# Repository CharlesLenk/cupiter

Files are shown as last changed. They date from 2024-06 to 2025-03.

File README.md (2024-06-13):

# Cupiter

Cupiter is a 3D Printable poseable action figure that resembles a robot. In this repository you'll find:
* [Printing and assembly instructions](instructions/README.md).
* The full [source code](src/README.md) for this project.

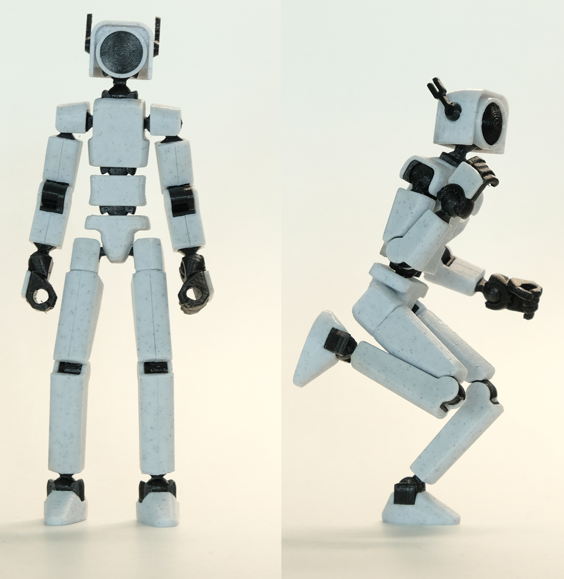
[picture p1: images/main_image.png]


## About

I've been working on Cupiter off and on (mostly off) for several years. At first, my goal was just to create a very simple desk toy inspired by Lego Bionicles. My CAD skills improved as I worked on the project though, which inspired me to keep going and redesigning at my current skill level. It's still possible to take it further, but I'm happy with Cupiter as it is now and am ready to share with the world.

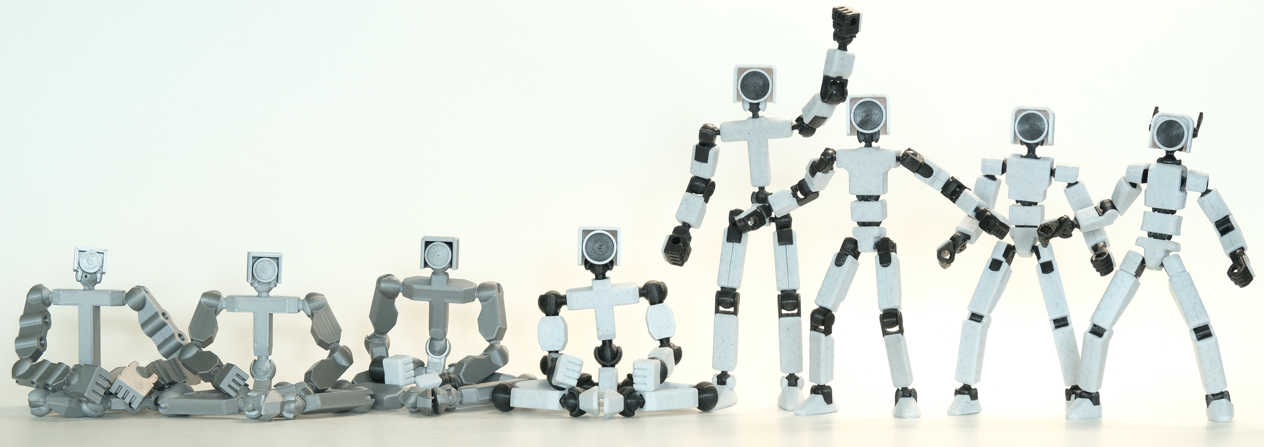
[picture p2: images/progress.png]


### Inspirations

* Lego Bionicles were some of my favorite toys growing up. The early designs of Cupiter were even lego-like, including pegs with snaps to attach additional parts, and simple ball and socket joints.
* Aaron Thomas' [Endo](https://www.toyforge.in/products/endo-the-skeleton). Endo is a more advanced project than mine, made by a more talented designer, but I did find it inspiring since if it was possible to push 3D printing this far, I knew what I was going for was achievable. This project heavily inspired the elbow and knee joints used for some of the middle versions of Cupiter.
* Soozafone's [Lucky 13](https://www.printables.com/model/148367-lucky-13-printable-jointed-figure). Lucky 13 came out a few years after I started this project and, after a mild round of despair having been beaten to the punch, it inspired me to revisit my work. Printing and assembling the two projects, you'll find the designs substantially different in construction, but I absolutely took visual cues from Lucky 13 like the second waist joint, posable shoulders, and more human-like proportions.

### Special Thanks

* I owe a lot to the developers and maintainers of [OpenSCAD](https://openscad.org/). It's been amazing having a project like this as a free resource.

## License
Source code and generated models are licensed under [CC-BY-4.0](https://creativecommons.org/licenses/by/4.0/).

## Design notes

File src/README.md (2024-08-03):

# About the Code
Because OpenSCAD is designed for parametric CAD, but the visual design for Cupiter is part sculpting, the code is a mix of well designed parameterized functions, and magic number hacks because something looked better if it was 0.2 millimeters larger. Where possible, I've attempted to have parts scale and adjust appropriately, but many edits will require manual tweaks for visual design.

## Cloning the Repository

This project uses a submodule for some common OpenSCAD code. If the submodule is not initialized, the `openscad-utilities` directory will be empty, and the project won't compile. To get the submodule code when cloning, add the `--recurse-submodules` option to the clone command. If you've already cloned the project, run the command `git submodule update --init` in the project root to pull down the submodule.

## Editing the Project
This project is written in native OpenSCAD and can be edited without any additional software, however I recommend using [VSCode](https://code.visualstudio.com/) with Leathong's [OpenSCAD extension](https://marketplace.visualstudio.com/items?itemName=Leathong.openscad-language-support).

OpenSCAD has an "Automatic Reload and Preview" option that will refresh the preview whenever a file is updated, even if the updates come from an external tool. In this way, you can have multiple instances of OpenSCAD showing previews of different parts in different files, and have all previews refresh to show your edits whenever you save in VSCode, which makes viewing changes to assemblies of multiple parts much easier.

### Navigating the Files
* antenna.scad
    * The antenna that go on the sides of the head options.
* arms.scad
    * The arms, including the shoulder that connects to the torso.
* assembly image map.scad
    * Provides a selector between multiple assembly views. Used by the script that exports assembly instruction images.
* assembly.scad
    * Provides an assembled view of the project.
* body.scad
    * The three main torso segments.
* camera head.scad
    * A head option that resembles a camera.
* feet.scad
    * The feet.
* globals.scad
    * Contains global variables for the project.
* hands.scad
    * All complex and simple hand options.
* legs.scad
    * The legs, including the hip that connects to the torso.
* limbs.scad
    * Shared code for the arms and legs.
* print map.scad
    * Imports all the other parts and rotates them into correct orientations for printing in order to simplify the export script.
* robot common.scad
    * Some common modules that didn't fit well into other files.
* snaps.scad
    * Code for the snap bumps that help hold parts together.
* space head.scad
    * An alternate head option.

## Generating the Parts

There are two options for generating the parts. Either through a provided export script, or manually through the OpenSCAD UI.

As of 2024, the OpenSCAD development preview uses a new rendering engine called Manifold, which is many times faster. When exporting or working on this project, it's recommended that you use a development snapshot of OpenSCAD with Manifold enabled. This project is tested as working with version `2024.05.02 (git 1057a82e9)` specifically, in the event that issues are encountered with newer versions.

### Exporting with the Script

In order to generate the parts, a [Python](https://www.python.org/) export script is provided in `src/python/stl_export.py`.

When first run, the export script will confirm the output directory and attempt to find OpenSCAD on your system. As long as OpenSCAD is installed in the standard applications directory for your system and you have a Desktop folder, the defaults provided should work without customization. The values are saved to `export.conf` in the project root, which can be edited directly if you need to change the OpenSCAD location or output directory.

The export will have the folder structure given in the [instructions](../instructions/README.md)

### Exporting Manually

This option is not recommended. `print map.scad` is invoked by the export script to generate each part. In this file, there is a large `if/else` condition where the call to generate each part can be seen. You can either write OpenSCAD code using these calls to build up a print plate, or the part selector can be manually edited to select each part, which can then be rendered and exported through the OpenSCAD UI like any other project.

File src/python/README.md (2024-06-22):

# Export Scripts

* stl_export.py
    * Exports STLs for the project.
* assembly_image_export.py
    * Exports images for the assembly guide.
* export_config.py
    * Functions for reading and writing export config values. Does nothing if run directly.

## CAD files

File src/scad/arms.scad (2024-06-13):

include <openscad-utilities/common.scad>
include <limbs.scad>
use <hands.scad>

elbow_max_angle = 160;

elbow_joint_offset = -2;

arm_armor_upper_len = arm_upper_len - ball_dist;
arm_armor_lower_len = arm_lower_len - ball_dist;

arm_width = 10;
arm_upper_top_len = 3.2;
arm_upper_bot_width_back = 1.1;
arm_lower_bot_width_front = 3.5;
arm_lower_bot_width_back = 3.4;

function elbow_max_angle() = elbow_max_angle;

module arm_assembly(
    frame_color = frame_color,
    armor_color = armor_color,
    with_armor = true,
    explode_frame = false,

    shoulder_armor = false,
    explode_shoulder_armor = false,
    arm_upper_armor = false,
    explode_arm_upper_armor = false,
    arm_lower_armor = false,
    explode_arm_lower_armor = false,

    hand = false,
    explode_hand = false,
    hand_armor = false,
    explode_hand_armor = false,

    arm_retract_angle = 0,
    elbow_angle = 0
) {
    shoulder_armor = with_armor && (explode_shoulder_armor ? true : shoulder_armor);
    arm_upper_armor = with_armor && (explode_arm_upper_armor ? true : arm_upper_armor);
    arm_lower_armor = with_armor && (explode_arm_lower_armor ? true : arm_lower_armor);
    hand_armor = with_armor && (explode_hand_armor ? true : hand_armor);
    hand = explode_hand ? true : hand;

    elbow_angle = explode_frame ? 40 : elbow_angle;

    explode_y = 22;
    frame_explode_y = explode_frame ? explode_y : 0;

    explode_z = 20;
    arm_upper_armor_explode_z = explode_arm_upper_armor ? explode_z : 0;
    arm_lower_armor_explode_z = explode_arm_lower_armor ? explode_z : 0;

    shoulder_armor_explode_z = explode_shoulder_armor ? explode_z : 0;

    hand_explode_y = explode_hand ? explode_y : 0;

    rotate(180) color(frame_color) shoulder();
    if (shoulder_armor) {
        translate([0, 0, -shoulder_armor_explode_z]) {
            rotate([0, 180, 180]) color(armor_color) shoulder_armor();
        }
        if(explode_shoulder_armor) {
            translate([0, 0, -shoulder_armor_explode_z/2]) {
                rotate([270, 0, 90]) assembly_arrow();
            }
        }
    }
    rotate([arm_retract_angle, 0, 0]) {
        translate([0, frame_explode_y, 0]) {
            rotate([0, 180, 0]) color(frame_color) arm_upper();
            if (arm_upper_armor) {
                reflect([0, 0, 1]) {
                    translate([0, 0, -arm_upper_armor_explode_z]) {
                        color(armor_color) arm_upper_armor();
                    }
                    if(explode_arm_upper_armor) {
                        translate([0, arm_upper_len/2, -arm_upper_armor_explode_z/2 - 2]) {
                            rotate([270, 0, 90]) assembly_arrow();
                        }
                    }
                }
            }
            if(explode_frame) {
                translate([0, -frame_explode_y/2]) rotate(180) assembly_arrow();
            }
        }
        rotate_with_offset_origin([elbow_joint_offset, arm_upper_len + frame_explode_y, 0], [0, 0, elbow_angle]) {
            if(explode_frame) {
                translate([elbow_joint_offset, arm_upper_len + 1.5 * frame_explode_y, 0]) {
                    rotate(180) assembly_arrow();
                }
            }
            translate([0, arm_upper_len + 2 * frame_explode_y]) {
                color(frame_color) arm_lower();
                if (arm_lower_armor) {
                    reflect([0, 0, 1]) {
                        translate([0, 0, -arm_lower_armor_explode_z]) {
                            color(armor_color) arm_lower_armor();
                        }
                        if(explode_arm_lower_armor) {
                            translate([0, arm_lower_len/2, -arm_lower_armor_explode_z/2 - 2]) {
                                rotate([270, 0, 90]) assembly_arrow();
                            }
                        }
                    }
                }
                if(hand) {
                    translate([0, arm_lower_len + hand_explode_y]) {
                        rotate([90, 180, 0]) {
                            mirror([0, 0, 1]) {
                                hand_assembly(
                                    frame_color = frame_color,
                                    armor_color = armor_color,
                                    armor = hand_armor,
                                    explode = explode_hand_armor
                                );
                            }
                        }
                        if(explode_hand) {
                            translate([0, -hand_explode_y/2]) assembly_arrow();
                        }
                    }
                }
            }
        }
    }
}

arm_upper_bot_width_front = get_limb_width_at_y(
    start_width = arm_width/2,
    end_width = arm_lower_bot_width_front,
    length = arm_armor_upper_len + arm_armor_lower_len - arm_upper_top_len,
    y = arm_armor_upper_len - arm_upper_top_len - hinge_armor_y_offset - 0.1
);
arm_lower_width_mid = get_limb_width_at_y(
    start_width = arm_width/2,
    end_width = arm_lower_bot_width_front,
    length = arm_armor_upper_len + arm_armor_lower_len - arm_upper_top_len,
    y = arm_armor_upper_len - arm_upper_top_len - hinge_armor_y_offset
);

module arm_upper_armor_blank() {
    limb_upper_armor_blank(
        length = arm_armor_upper_len,
        height = segment_height + 2.7,
        top_width = arm_width,
        top_back_length = arm_upper_top_len,
        bottom_front_width = arm_upper_bot_width_front,
        bottom_back_width = arm_upper_bot_width_back,
        joint_offset = elbow_joint_offset
    );
}

module arm_lower_armor_blank() {
    limb_lower_armor_blank(
        length = arm_armor_lower_len,
        height = segment_height + 2.7,
        top_width_front = arm_lower_width_mid,
        width_back = arm_lower_bot_width_back,
        bottom_front_width = arm_lower_bot_width_front,
        joint_offset = elbow_joint_offset
    );
}

module shoulder_socket(is_cut = false) {
    height = segment_height + (is_cut ? segment_cut_height_offset : 0);
    width = socket_d + (is_cut ? segment_cut_width_offset : 0);
    cut_d = is_cut ? 0.2 : 0;

    d = socket_d + 0.5 + cut_d;
    difference() {
        apply_socket_cut(hip_shoulder_tolerance, is_cut = is_cut) {
            rounded_socket_blank(is_cut);
        }
        if (!is_cut) {
            hull() {
                cylinder(d = 4, h = 10);
                rotate([-25, 0, 0]) cylinder(d = 4, h = 10);
            }
        }
        armor_snap_inner(
            length = 4,
            target_width = socket_d,
            depth = 0.6,
            is_cut = !is_cut,
            width_cut_adjust = 0.2
        );
    }
}

module shoulder(is_cut = false) {
    shoulder_socket(is_cut);
    translate([0, socket_r + ball_dist]) {
        rotate(180) ball(is_cut);
    }
}

module shoulder_armor() {
    height = segment_height + 2.6;

    difference() {
        minkowski() {
            armor_blank(socket_d - edge_d + 2.4, segment_height - edge_d + 2.4);
            sphere(d = 1);
        }
        rotate([0, 180, 0]) shoulder(true);
        translate([0, 0, -1.5 * segment_height]) {
            linear_extrude(segment_height) {
                projection(cut = true) {
                    translate([0, 0, segment_height/2]) shoulder(true);
                }
            }
        }
    }

    module armor_blank(x, z) {
        cylinder_length = socket_d/2 - edge_d/2;
        h_ext = 1.2;

        intersection() {
            hull() {
                rotate(180) {
                    rotate_extrude(angle = 180) {
                        intersection() {
                            armor_2d(x, z);
                            translate([0, -z/2]) square([x/2, z]);
                        }
                    }
                }
                rotate([270, 0, 0]) linear_extrude(cylinder_length) armor_2d(x, z);


                translate([0, cylinder_length, h_ext/2]) {
                    rotate([270, 0, 0]) linear_extrude(0.001) armor_2d(x, z + h_ext, d = 6);
                }
            }
            shoulder_cut(
                x,
                pos_y = 2.9,
                neg_y = cylinder_length,
                pos_z = segment_height/2 + h_ext + 1.2 - edge_d/2,
                neg_z = segment_height/2 - edge_d/2 + 0.3,
                ext = 0,
                d = 3
            );
        }
    }
}

module arm_upper(is_cut = false) {
    limb_segment(
        length = arm_upper_len,
        end1_len = ball_dist,
        end2_len = hinge_socket_d/2,
        is_cut = is_cut,
        snaps = true,
        cross_brace = true
    ) {
        ball(is_cut);
        hinge_socket(elbow_joint_offset, is_cut);
    };
}

module arm_upper_armor(is_top = false) {
    apply_armor_cut(is_top) {
        translate([0, ball_dist]) arm_upper_armor_blank();
        mirror([1, 0, 0]) arm_upper(true);
    }
}
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

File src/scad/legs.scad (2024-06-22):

include <openscad-utilities/common.scad>
include <globals.scad>
include <limbs.scad>
use <feet.scad>

knee_joint_offset = -2.3;
knee_max_angle = 165;

leg_upper_top_width = socket_d + 2.4;
upper_thigh_length_back = 6.5;
lower_thight_width_back = 1.2;
leg_lower_armor_len = leg_lower_len - ball_dist;
lower_leg_back_width = 3.7;
lower_leg_lower_width_front = 4;
armor_z = segment_height + 3;

rotator_peg_l = 8;
rotator_peg_d = segment_height + 0.4;
rotator_socket_l = rotator_peg_l + socket_shell_width;
rotator_socket_d = rotator_peg_d + 2 * socket_shell_width + leg_rotator_tolerance;

leg_upper_bot_width_front = get_limb_width_at_y(
    start_width = leg_upper_top_width/2,
    end_width = lower_leg_lower_width_front,
    length = leg_upper_len + leg_lower_armor_len,
    y = leg_upper_len - hinge_armor_y_offset - 0.1
);
leg_lower_width_mid = get_limb_width_at_y(
    start_width = leg_upper_top_width/2,
    end_width = lower_leg_lower_width_front,
    length = leg_upper_len + leg_lower_armor_len,
    y = leg_upper_len - hinge_armor_y_offset
);

function knee_max_angle() = knee_max_angle;

module leg_assembly(
    frame_color = frame_color,
    armor_color = armor_color,
    with_armor = true,
    explode_frame = false,

    hip_armor = false,
    explode_hip_armor = false,
    leg_upper_armor = false,
    explode_leg_upper_armor = false,
    leg_lower_armor = false,
    explode_leg_lower_armor = false,

    foot_socket = false,
    explode_foot_socket = false,
    foot = false,
    explode_foot = false,

    knee_angle = 0
) {
    hip_armor = with_armor && (explode_hip_armor ? true : hip_armor);
    leg_upper_armor = with_armor && (explode_leg_upper_armor ? true : leg_upper_armor);
    leg_lower_armor = with_armor && (explode_leg_lower_armor ? true : leg_lower_armor);
    foot_socket = explode_foot_socket ? true : foot_socket;
    foot = explode_foot ? true : foot;

    hip_offset = socket_d/2 + hip_peg_extension;
    knee_angle = explode_frame ? 40 : knee_angle;

    explode_y = 22;
    explode_z = 20;

    frame_explode_y = explode_frame ? explode_y : 0;
    hip_armor_explode_z = explode_hip_armor ? explode_z : 0;

    foot_socket_explode_y = explode_foot_socket ? explode_y : 0;
    foot_explode_y = explode_foot ? explode_y : 0;

    leg_upper_armor_explode_z = explode_leg_upper_armor ? explode_z : 0;
    leg_lower_armor_explode_z = explode_leg_lower_armor ? explode_z : 0;

    color(frame_color) hip();
    if (hip_armor) {
        translate([0, 0, hip_armor_explode_z]) {
            color(armor_color) hip_armor();
        }
        if(explode_hip_armor) {
            translate([0, 0, hip_armor_explode_z/2]) {
                rotate([90, 0, 90]) assembly_arrow();
            }
        }
    }
    translate([0, hip_offset + frame_explode_y, 0]) {
        rotate([0, 180, 0]) color(frame_color) leg_upper();
        if (leg_upper_armor) {
            reflect([0, 0, 1]) {
                translate([0, 0, -leg_upper_armor_explode_z]) {
                    color(armor_color) leg_upper_armor();
                }
                if(explode_leg_upper_armor) {
                    translate([0, leg_upper_len/2, -leg_upper_armor_explode_z/2 - 2]) {
                        rotate([270, 0, 90]) assembly_arrow();
                    }
                }
            }
        }
        if(explode_frame) {
            translate([0, -frame_explode_y/2 + 4]) rotate(180) assembly_arrow();
        }
    }
    rotate_with_offset_origin([knee_joint_offset, hip_offset + leg_upper_len + frame_explode_y, 0], [0, 0, knee_angle]) {
        if(explode_frame) {
            translate([knee_joint_offset, hip_offset + leg_upper_len + 1.5 * frame_explode_y, 0]) {
                rotate(180) assembly_arrow();
            }
        }
        translate([0, hip_offset + leg_upper_len + 2 * frame_explode_y]) {
            color(frame_color) leg_lower();
            translate([0, foot_socket_explode_y]) {
                if(foot_socket) {
                    translate([0, leg_lower_len, 0]) {
                        rotate([0, 90, 0]) {
                            foot_assembly(
                                frame_color = frame_color,
                                armor_color = armor_color,
                                foot_socket = foot_socket,
                                foot = foot,
                                explode_foot = explode_foot
                            );
                        }
                    }
                    if(explode_foot_socket) {
                        translate([0, leg_lower_len - foot_socket_explode_y/2, 0]) {
                            assembly_arrow();
                        }
                    }
                }
            }
            if (leg_lower_armor) {
                reflect([0, 0, 1]) {
                    translate([0, 0, -leg_lower_armor_explode_z]) {
                        color(armor_color) leg_lower_armor();
                    }
                    if(explode_leg_lower_armor) {
                        translate([0, leg_upper_len/2, -leg_lower_armor_explode_z/2 - 2]) {
                            rotate([270, 0, 90]) assembly_arrow();
                        }
                    }
                }
            }
        }
    }
}

module leg_upper_armor_blank() {
    limb_upper_armor_blank(
        length = leg_upper_len,
        height = armor_z,
        top_width = leg_upper_top_width,
        top_back_length = upper_thigh_length_back,
        bottom_front_width = leg_upper_bot_width_front,
        bottom_back_width = lower_thight_width_back,
        joint_offset = knee_joint_offset
    );
}

module leg_lower_armor_blank() {
    limb_lower_armor_blank(
        length = leg_lower_armor_len,
        height = armor_z,
        top_width_front = leg_lower_width_mid,
        width_back = lower_leg_back_width,
        bottom_front_width = lower_leg_lower_width_front,
        joint_offset = knee_joint_offset
    );
}

module hip_socket(is_cut = false) {
    height = segment_height + (is_cut ? segment_cut_height_offset : 0);
    width = socket_d + (is_cut ? segment_cut_width_offset : 0);
    cut_d = is_cut ? 0.2 : 0;

    d = socket_d + 0.5 + cut_d;
    difference() {
        apply_socket_cut(hip_shoulder_tolerance, is_cut = is_cut) {
            rounded_socket_blank(is_cut);
        }
        armor_snap_inner(
			length = 4,
			target_width = socket_d,
            depth = 0.5,
			is_cut = !is_cut,
			width_cut_adjust = 0.2
		);
    }
}

module hip(is_cut = false) {
    hip_socket(is_cut);
    translate([0, socket_d/2 + hip_peg_extension]) {
        rotate(180) rotator_peg(rotator_peg_l, hip_peg_extension, is_cut);
    }
}

module hip_armor() {
    difference() {
        minkowski() {
            armor_blank(socket_d + 2.4 - edge_d, armor_z - edge_d);
            sphere(d = edge_d);
        }
        rotate([-90, 0, 0]) {
            peg_cut_d = rotator_peg_d + 0.1;
            tab_cut_x = rotator_peg_d - 1.5;
            peg_cut_len = socket_d;
            cylinder(d = peg_cut_d, h = peg_cut_len);
            translate([-tab_cut_x/2, 0]) cube([tab_cut_x, peg_cut_d + 10, peg_cut_len]);
        }
        hip(true);
        translate([0, 0, -1.5 * segment_height]) {
            linear_extrude(segment_height) {
                projection(cut = true) {
                    translate([0, 0, segment_height/2]) hip(true);
                }
            }
        }
    }

    module armor_blank(x, z) {
        intersection() {
            union() {
                rotate_extrude() {
                    intersection() {
                        armor_2d(x, z);
                        translate([0, -z/2]) square([x/2, z]);
                    }
                }
                rotate([270, 0, 0]) linear_extrude(socket_d/2 + hip_armor_tab_width - edge_d/2) armor_2d(x, z);
            }
            shoulder_cut(
                x,
                pos_y = 2.7,
                neg_y = socket_d/2 + hip_armor_tab_width - edge_d/2,
                pos_z = armor_z/2 - edge_d/2,
                neg_z = segment_height/2 - edge_d/2 + 0.3,
                ext = 0,
                d = 3
            );
        }
    }
}

module leg_upper(is_cut = false) {
    limb_segment(
        length = leg_upper_len,
        end1_len = rotator_socket_l,
        end2_len = hinge_socket_d/2,
        is_cut = is_cut,
        snaps = true,
        cross_brace = true
    ) {
        rotator_socket(rotator_peg_l, is_cut);
        hinge_socket(knee_joint_offset, is_cut);
    };
}

module leg_upper_armor(is_top = false) {
    apply_armor_cut(is_top) {
        leg_upper_armor_blank();
        rotate([0, 180, 0]) leg_upper(true);
    }
}

module leg_lower(is_cut = false) {
    limb_segment(
        length = leg_lower_len,
        end1_len = hinge_peg_size/2,
        end2_len = ball_dist,
        is_cut = is_cut,
        snaps = true,
        cross_brace = true
    ) {
        hinge_peg_holder(knee_joint_offset, is_cut);
        ball(is_cut);
    };
}
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

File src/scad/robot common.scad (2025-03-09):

include <openscad-utilities/common.scad>
include <globals.scad>
use <openscad-utilities/arrow.scad>
use <snaps.scad>

socket_opening_angle = 115;

module apply_socket_cut(ball_offset = 0, socket_angle = 0, cut_angle = socket_opening_angle, is_cut = false) {
    height = segment_height + (is_cut ? segment_cut_height_offset : 0);
    width = socket_d + (is_cut ? segment_cut_width_offset : 0);

    difference() {
        children();
        if (!is_cut) rotate(socket_angle) socket_cut(cut_angle, ball_offset);
    }
    if (is_cut) ball_for_armor_subtractions();
}

module socket_cut(cut_angle = socket_opening_angle, ball_offset) {
    translate([0, 0, -socket_d/2]) {
        rotate(180) wedge(cut_angle, socket_d/2, socket_d);
    }
    sphere(d = ball_d + ball_offset);
    hull () {
        cylinder(h = socket_d, d = 4, center = true);
        translate([0, -socket_d/2, 0]) {
            cylinder(h = socket_d, d = 4, center = true);
        }
    }
}

module rounded_socket_blank(is_cut = false, cylinder_length, has_cylinder = true) {
    height = is_cut ? segment_cut_height : segment_height;
    socket_width = is_cut ? socket_d + 0.25 : socket_d;
    cylinder_length = is_undef(cylinder_length) ? socket_width/2 : cylinder_length;
    round_from_edge = 2;
    d = 7;

    rotate_extrude() {
        intersection() {
            armor_2d(socket_width, height, round_from_edge, d);
            translate([0, -height/2]) square([socket_width/2, height]);
        }
    }
    if (has_cylinder) {
        rotate([270, 0, 0]) linear_extrude(cylinder_length) {
            armor_2d(socket_width, height, round_from_edge, d);
        }
    }
}

module ball_for_armor_subtractions() sphere(d = ball_d + 0.2);

module ball(is_cut = false, tab_extension = 0) {
    if (is_cut) {
        translate([-segment_cut_width/2, 0, -segment_cut_height/2]) {
            cube([segment_cut_width, ball_d/2 + ball_tab_len + tab_extension, segment_cut_height]);
        }
    } else {
        xy_cut(ball_cut_height, size = ball_d) {
            sphere(d = ball_d);
        }
        translate([-segment_width/2, 0]) {
            rotate([0, 90, 0]) {
                linear_extrude(segment_width){
                    polygon(
                        [
                            [segment_height/4, 0],
                            [segment_height/4, ball_d/2],
                            [segment_height/2, ball_d/2 + ball_tab_len],
                            if (tab_extension > 0) [segment_height/2, ball_d/2 + ball_tab_len + tab_extension],

                            if (tab_extension > 0) [-segment_height/2, ball_d/2 + ball_tab_len + tab_extension],
                            [-segment_height/2, ball_d/2 + ball_tab_len],
                            [-segment_height/4, ball_d/2],
                            [-segment_height/4, 0],
                        ]
                    );
                }
            }
        }
    }
}

module apply_armor_cut(is_top = false) {
    armor_tightness_adjust = 0.05;

    xy_cut(armor_tightness_adjust, from_top = true, size = 100) {
        rotate([0, is_top ? 180 : 0, 0]) {
            difference() {
                children(0);
                children(1);
            }
        }
    }
}

module socket_with_snaps(is_cut = false) {
    cut_adjust = is_cut ? 0.15 : 0;
    height = is_cut ? segment_cut_height : segment_height;

    tab_len = 3.5;
    tab_width = 4;

    apply_socket_cut(head_and_foot_tolerance, is_cut = is_cut) {
        rounded_socket_blank(is_cut);
    }

    translate([0, socket_d/2]) snaps_tabs(tab_width, tab_len, height, is_cut);
}

module cross_brace(depth, target_width, is_cut) {
    height = is_cut ? segment_cut_height : segment_height;
    cut_adjust = is_cut ? 0.1 : 0;

    translate([0, 0, -height/2]) {
        linear_extrude(height) {
            hull() {
                reflect([1, 0, 0]) {
                    translate([target_width/2, 0]) {
                        circle(d = depth + cut_adjust);
                    }
                }
            }
        }
    }
}

module shoulder_cut(x, pos_y, neg_y, pos_z, neg_z, ext, d) {
    rotate([0, 270, 0]) {
        translate([-neg_z, -pos_y, -x/2]) {
            linear_extrude(x) {
                hull() {
                    difference() {
                        square([pos_z + neg_z, pos_y + neg_y]);
                        square([d/2, d/2]);
                    }
                    translate([d/2, d/2 - ext]) circle(d = d);
                }
            }
        }
    }
}

module armor_section(x, y, z, left_d, right_d, center = false, round_len = 3) {
    translate([0, center ? -y/2 : 0]) {
        rotate([270, 0, 0]) {
            linear_extrude(y) {
                armor_2d(x, z, round_len, 8, left_d, right_d);
            }
        }
    }
}

module armor_2d(x, y, round_len = 3, d = 8, left_d, right_d) {
    mid = y - 2 * round_len;
    left_d = is_positive(left_d) ? left_d : d;
    right_d = is_positive(right_d) ? right_d : d;

    hull() {
        reflect([0, 1, 0]) {
            translate([0, mid/2]) circle_corner(x/2, round_len, left_d/2);
            mirror([1, 0, 0]) translate([0, mid/2]) circle_corner(x/2, round_len, right_d/2);
        }
    }
}

module circle_corner(x, y, r) {
    intersection() {
        translate([-r + x, r > y ? 0 : -r + y]) circle(r);
        square([x, y]);
    }
}

module square_with_chamfers(x, y, chamfer_x, chamfer_y) {
    polygon(
        [
            [x/2, y/2 - chamfer_y],
            [x/2 - chamfer_x, y/2],
            [-x/2 + chamfer_x, y/2],
            [-x/2, y/2 - chamfer_y],
            [-x/2, -y/2 + chamfer_y],
            [-x/2 + chamfer_x, -y/2],
            [x/2 - chamfer_x, -y/2],
            [x/2, -y/2 + chamfer_y],
        ]
    );
}

module assembly_arrow() {
    arrow(head_width = 4, length = 7, center = true);
}

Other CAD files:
src/scad/antenna.scad
robot/body.scad
robot/hands.scad
robot/head.scad
robot/limbs.scad
robot/print map.scad
robot/robot common.scad
robot/snaps.scad
src/scad/assembly image map.scad
src/scad/assembly.scad
src/scad/body.scad
src/scad/camera head.scad
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

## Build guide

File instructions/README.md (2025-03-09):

# Instructions

## Printing

All parts are designed to be printed on standard consumer grade FDM printers with a 0.4mm nozzle and 0.15mm layer height. Most parts, with the exception of some hand options, should be printed without supports or brims for the best result.

PETG or similar filament is recommended. It may be possible to print some parts in PLA, however many parts will be too brittle for assembly, and the joints will loosen very fast because PLA deforms more under strain.

### Project Folders

The parts are divided into a number of folders, some of which contain optional parts. If multiple copies of a part are needed, the folders will contain the correct number of copies, so you can simply plate all files in a given folder without worrying about adjusting the count of any parts.

The `frame` and `armor` folders contain all parts other than the hand options.
* `frame`
  * Contains the stick-figure frame for the robot, plus a couple additional parts like the lens for the eye which can look good printed in the same color. For best results, enable adaptive layer height for the lens if your slicer supports it.
* `armor`
  * Contains all the armor parts that clip over the frame.

Two main options are available for hands, and the best one to choose depends on the capabilities of your printer. Pick at least one set of hands.
* `hand_simple`
  * A blocky hand in a grip pose that is designed to print without supports. `hand_simple_armor` contains the armor for the back of the hands.
* `hand_complex_grip`
  * A more detailed hand in a grip pose. Requires supports to print; Organic supports will produce the best result. `hand_complex_armor` contains the armor for the back of the hands

The `alternatives` folder contains additional options for some parts.
* `hand_complex_posed`
  * A series of alternate, more detailed hands in a variety of poses. Each pose has a right and left hand version so they can be mixed and matched. All hand require supports to print; Organic supports will produce the best result. One set of `hand_complex_armor` should be printed for each set of hands.
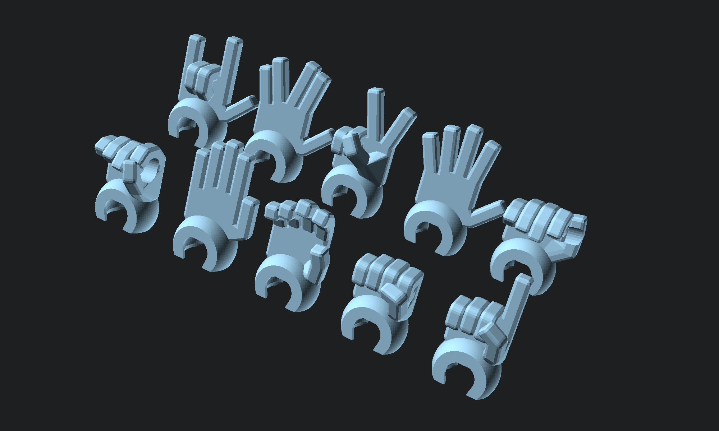
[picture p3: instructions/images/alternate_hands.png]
  
* `space_head`
  * An alternate head option that can be used instead of the camera head. The `accessories` folder contains the required antenna and visor.
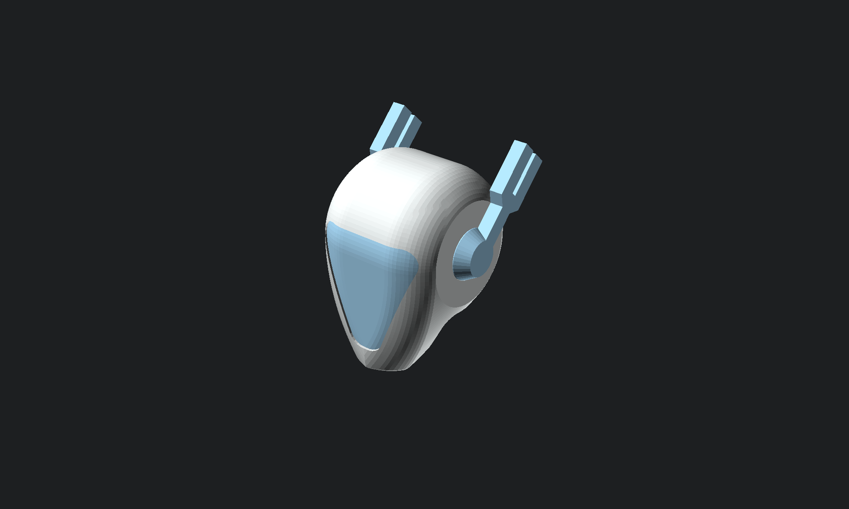
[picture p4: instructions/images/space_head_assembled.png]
  

## Assembly

All parts are designed to snap together or hold together using tension, and no tools or glue are needed for assembly.

Some parts can be much harder to assemble based on the order in which they are assembled. Following the steps below is recommended, or at least assembling the frame before attaching the armor.

### Assembly Tips

Snapping together the ball and socket joints is easier if you angle the flat side of the ball toward the edge of the socket.

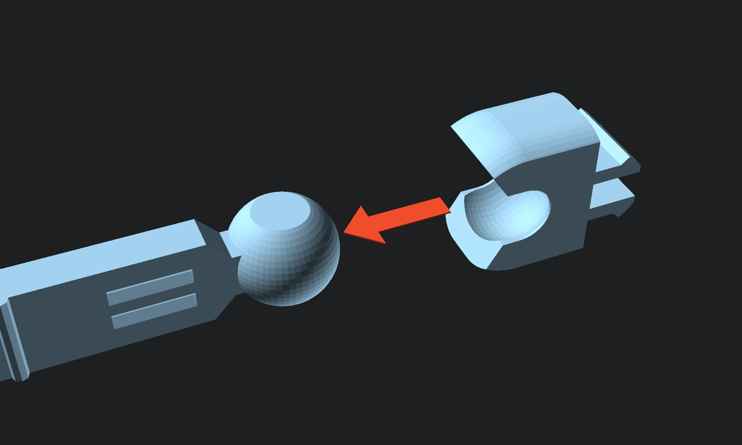
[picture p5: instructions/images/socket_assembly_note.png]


Some parts look similar and it can be hard to tell the correct orientation. From left to right, the below image shows:
* The shoulder from the top.
* The shoulder from the bottom. Note the deeper cut on the socket. This part should face toward the armpit when the arm is assembled.
* The waist. Note the slightly longer stem on the ball, double snap indent, and cross-brace to prevent slipping.

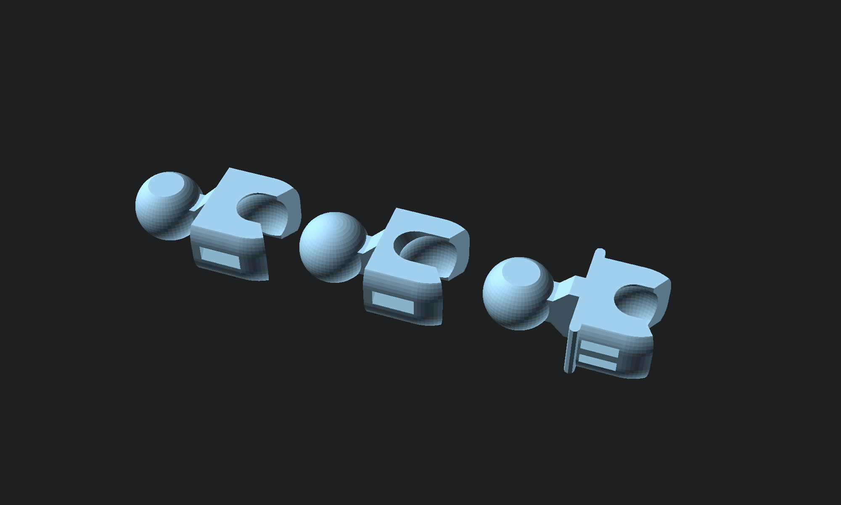
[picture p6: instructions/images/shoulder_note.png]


### Arm Assembly (2x)
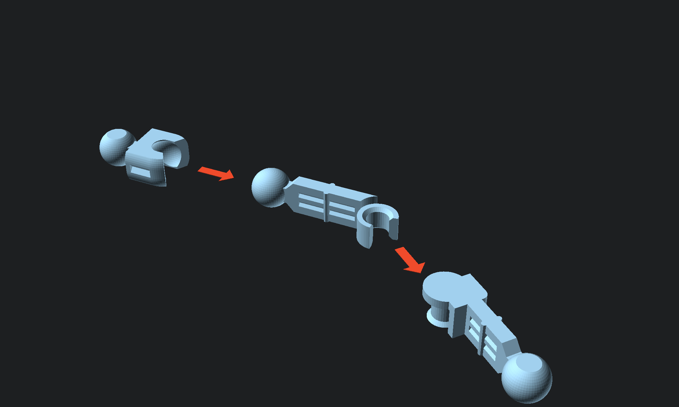
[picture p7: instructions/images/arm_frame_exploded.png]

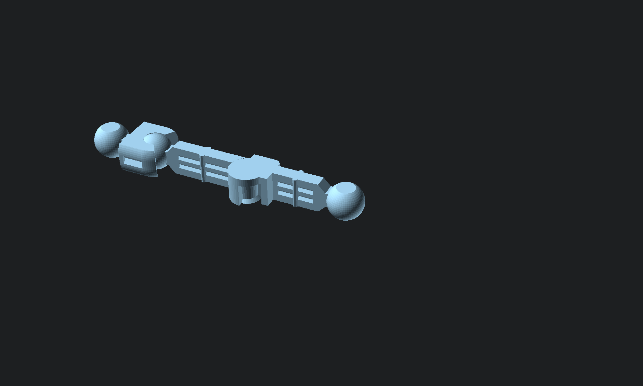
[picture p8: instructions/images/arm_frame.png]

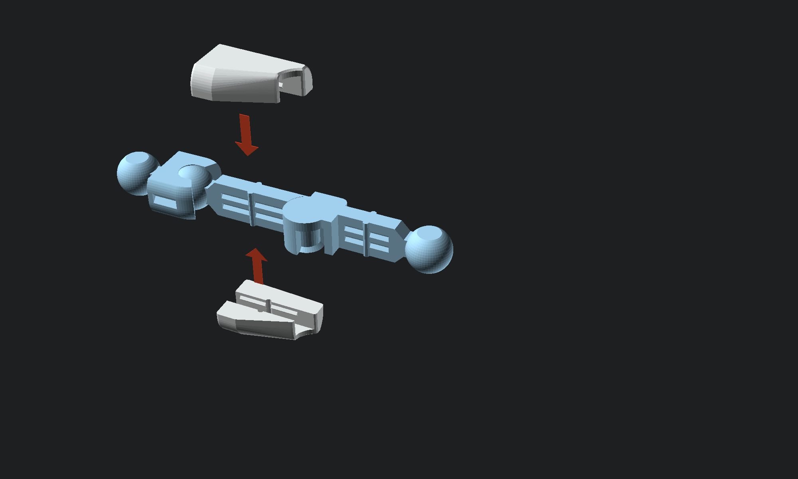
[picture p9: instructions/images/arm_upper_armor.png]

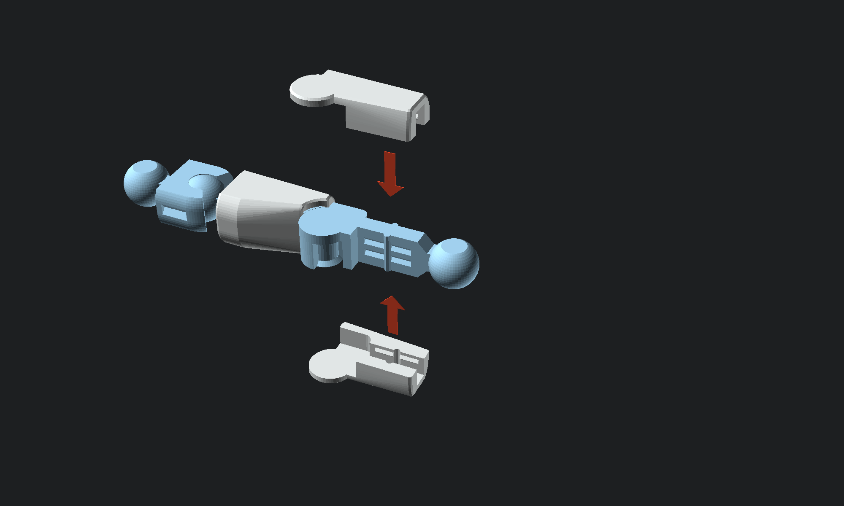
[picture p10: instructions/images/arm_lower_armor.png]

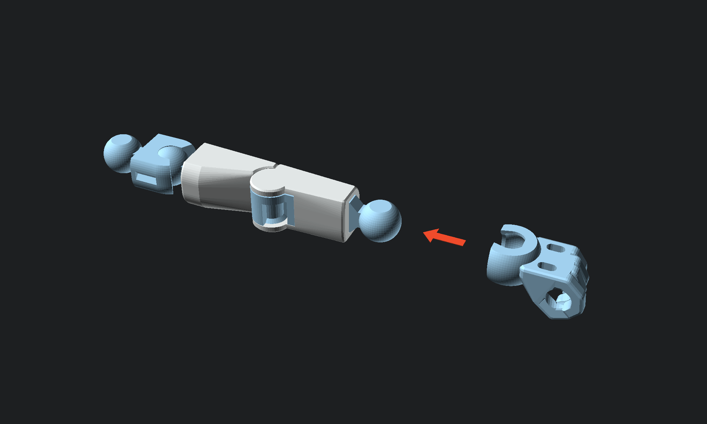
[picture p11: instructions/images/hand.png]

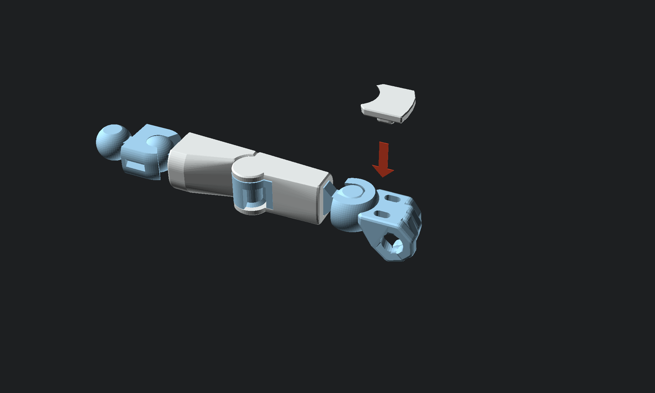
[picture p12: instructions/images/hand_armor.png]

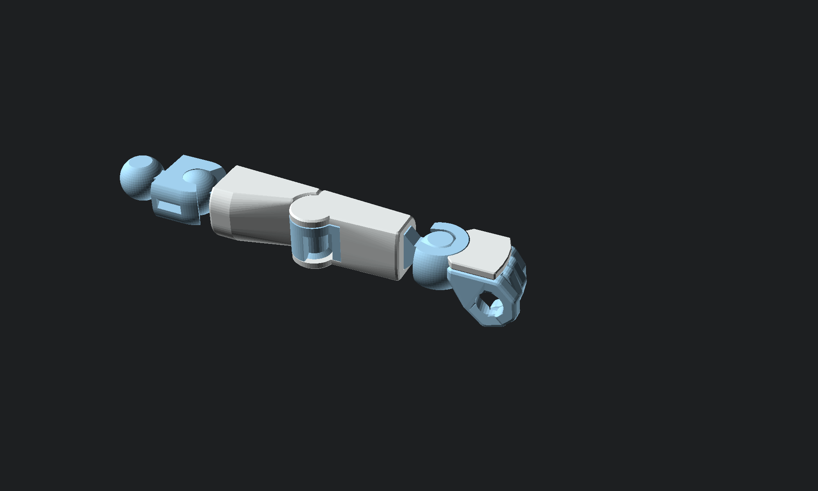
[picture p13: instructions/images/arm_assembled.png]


### Upper Body Assembly
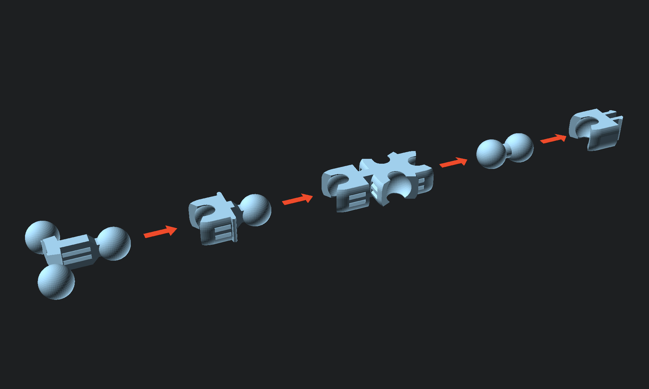
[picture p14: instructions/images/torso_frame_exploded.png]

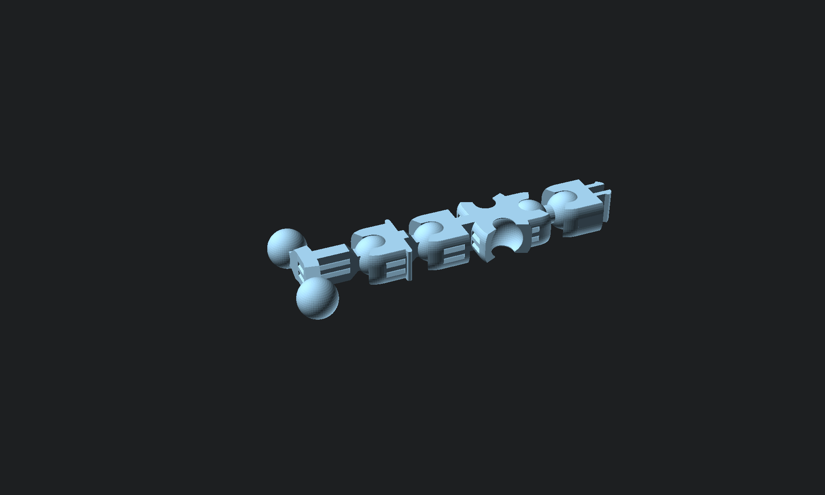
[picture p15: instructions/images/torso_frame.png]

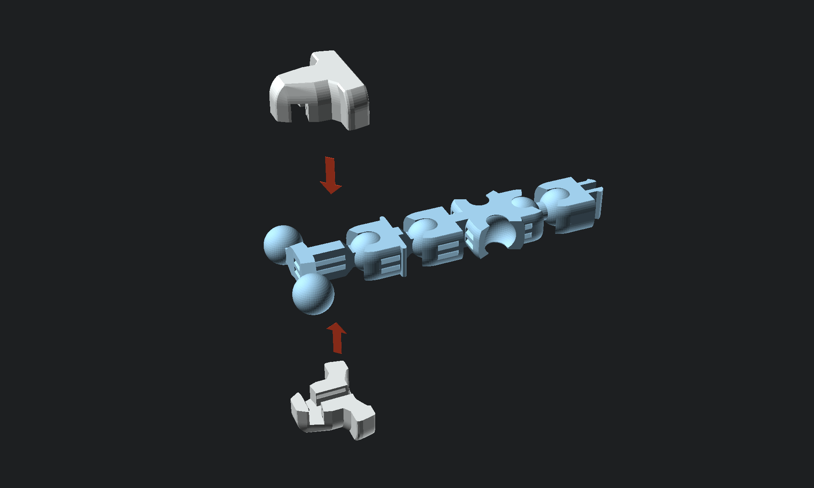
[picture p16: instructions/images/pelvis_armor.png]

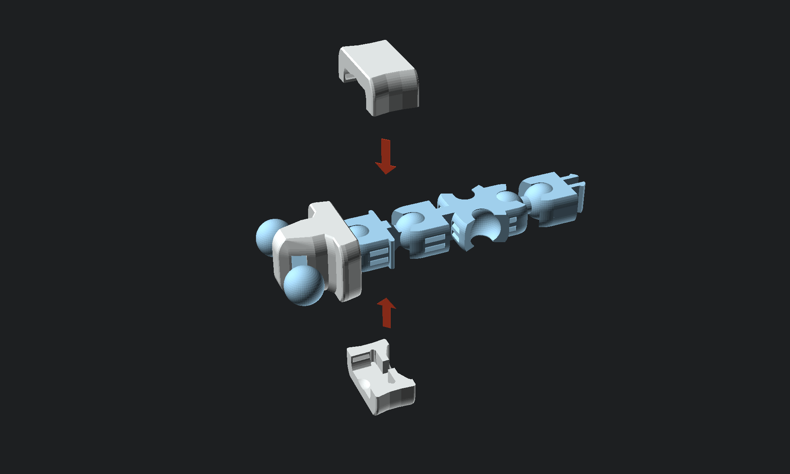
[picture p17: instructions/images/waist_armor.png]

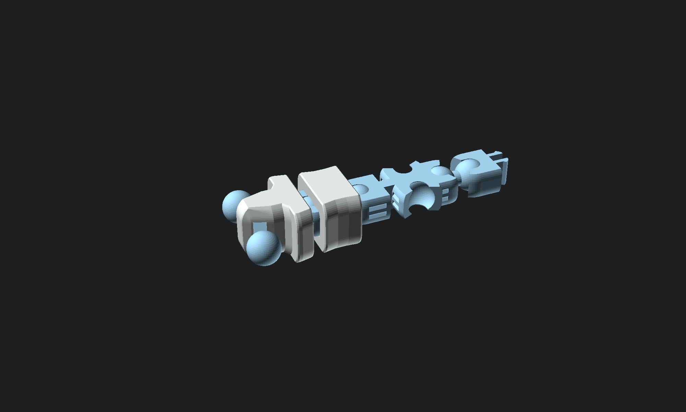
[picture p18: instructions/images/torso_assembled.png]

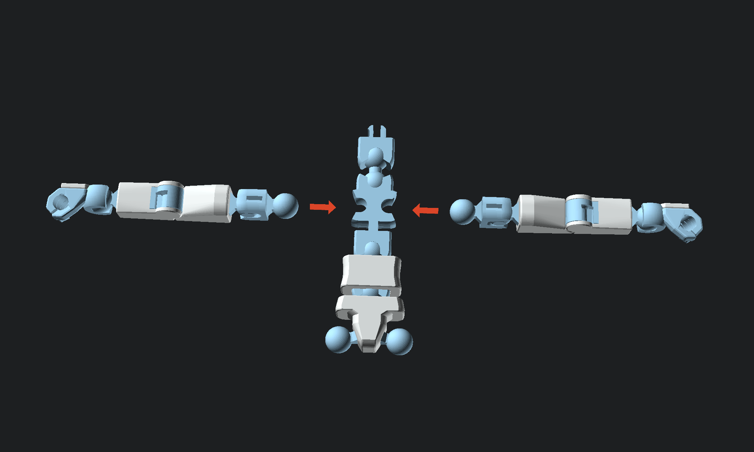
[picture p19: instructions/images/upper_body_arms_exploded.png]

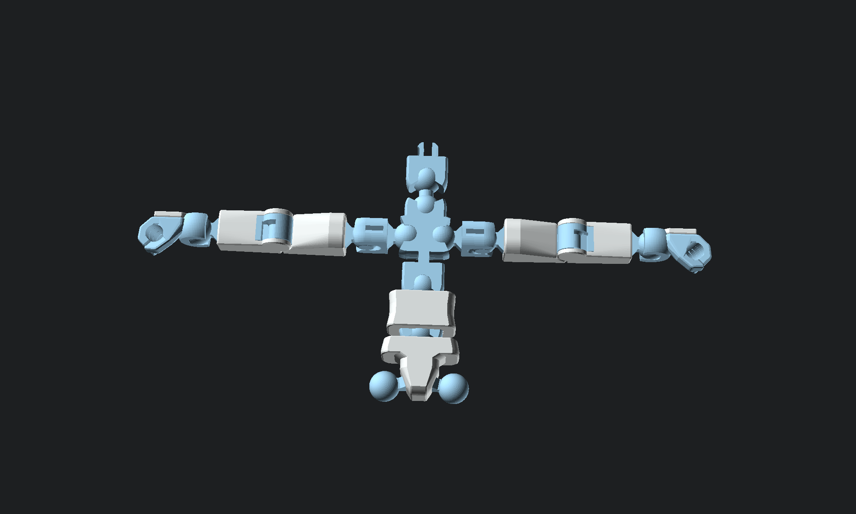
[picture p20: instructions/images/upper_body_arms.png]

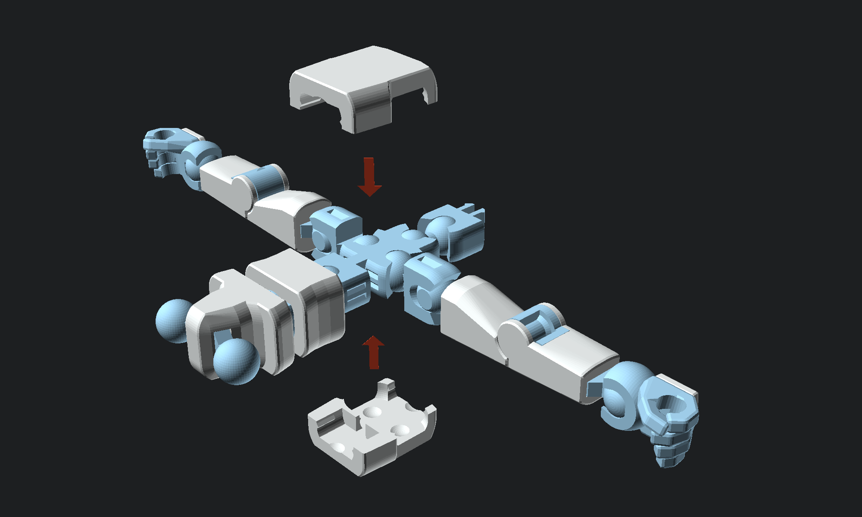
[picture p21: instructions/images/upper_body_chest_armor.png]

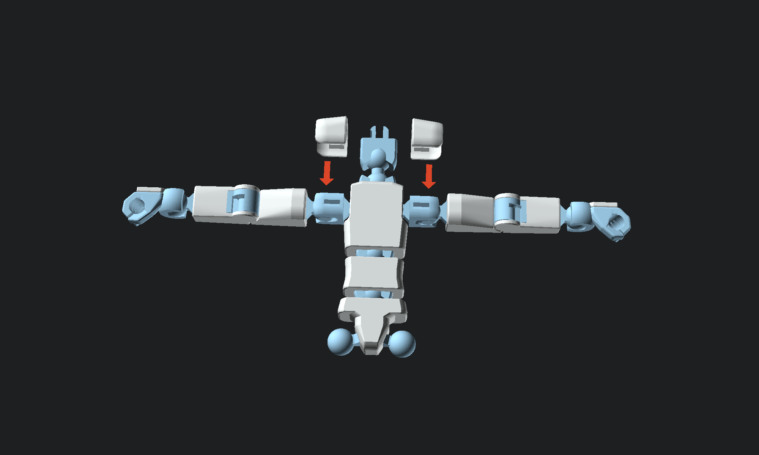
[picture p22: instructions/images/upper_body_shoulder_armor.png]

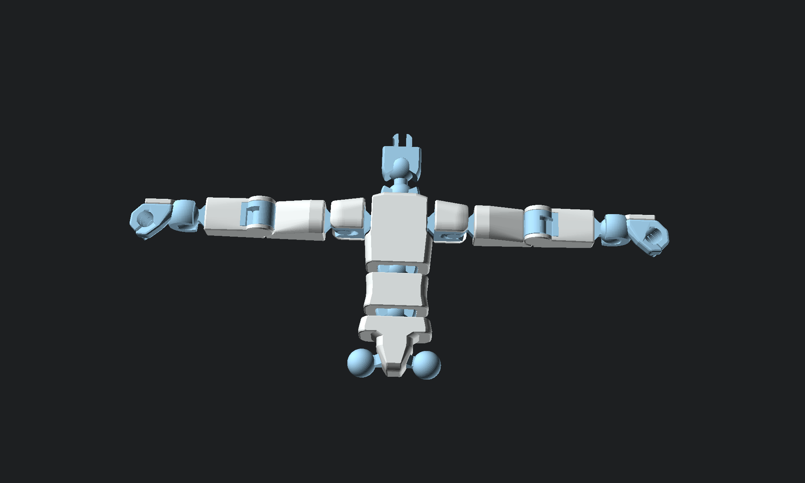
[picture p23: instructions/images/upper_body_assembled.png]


### Leg Assembly (2x)
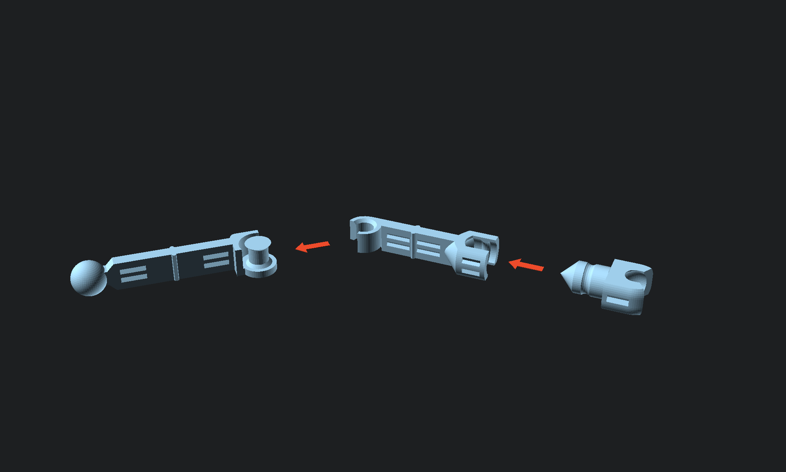
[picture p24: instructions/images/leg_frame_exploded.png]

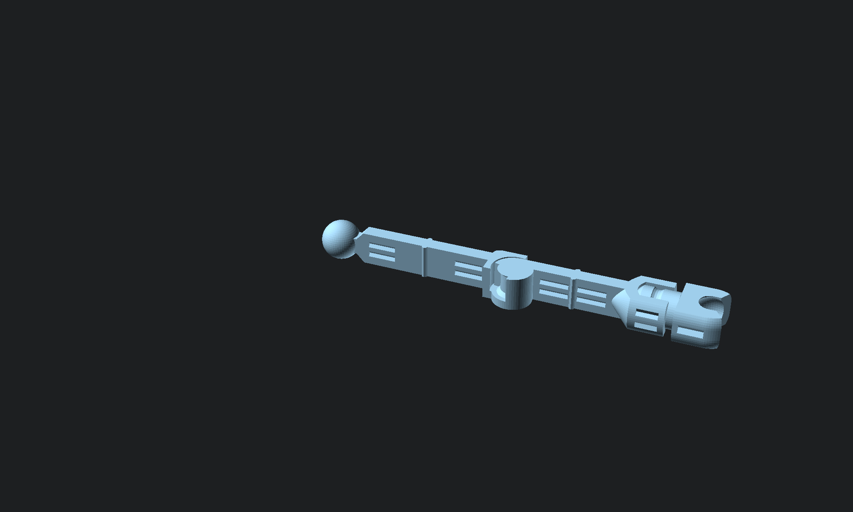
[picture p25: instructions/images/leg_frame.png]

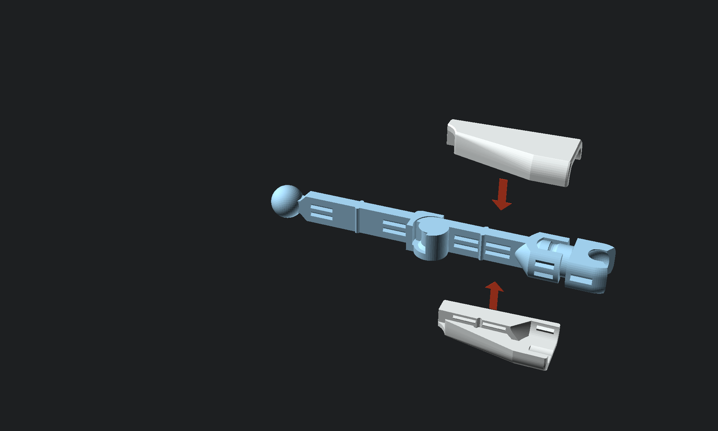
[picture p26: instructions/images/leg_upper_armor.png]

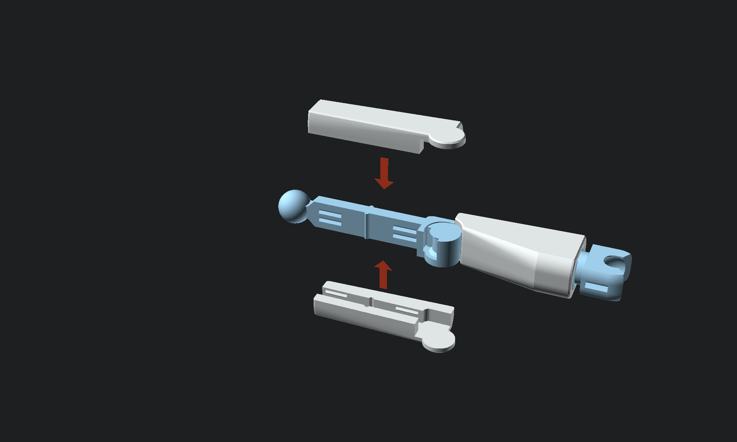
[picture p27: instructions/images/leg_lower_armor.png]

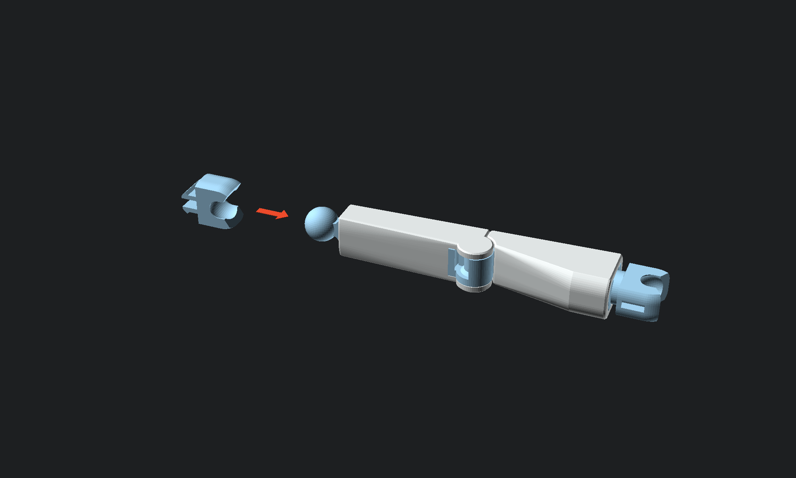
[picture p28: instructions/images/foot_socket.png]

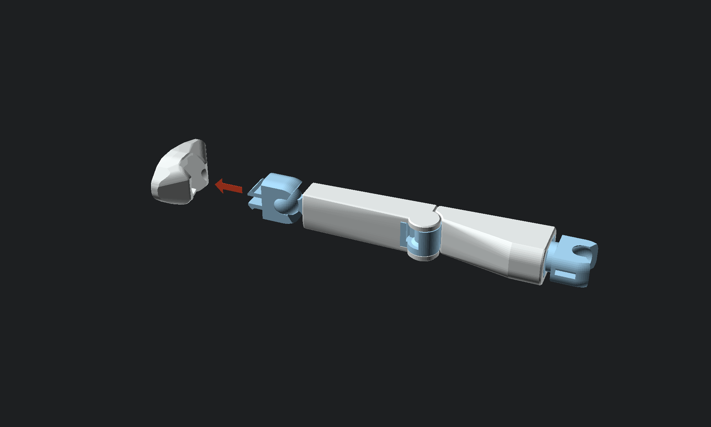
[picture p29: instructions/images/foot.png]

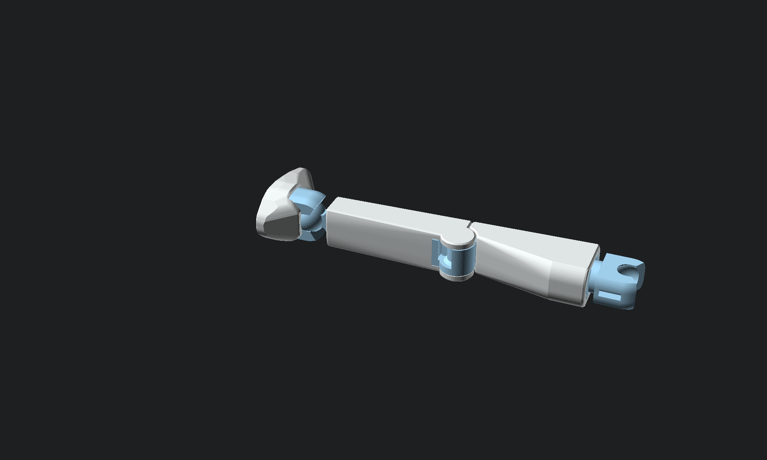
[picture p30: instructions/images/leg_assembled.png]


### Body Assembly
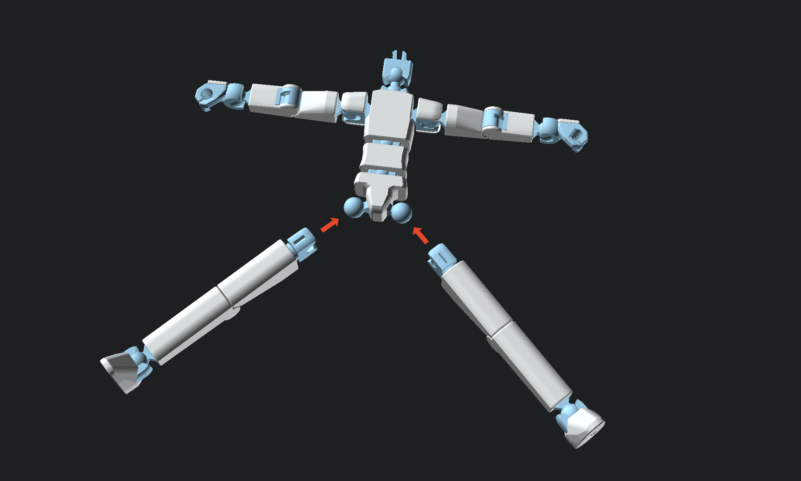
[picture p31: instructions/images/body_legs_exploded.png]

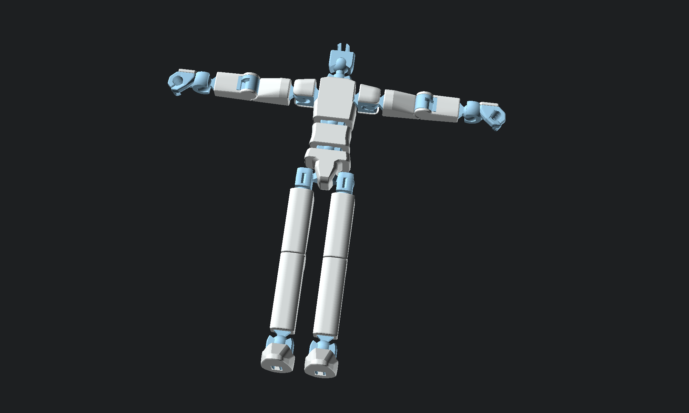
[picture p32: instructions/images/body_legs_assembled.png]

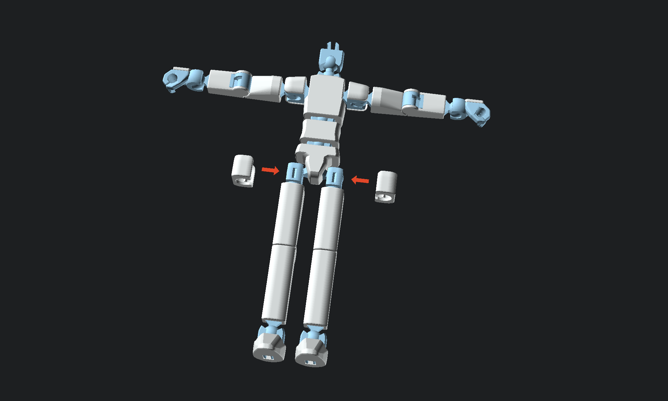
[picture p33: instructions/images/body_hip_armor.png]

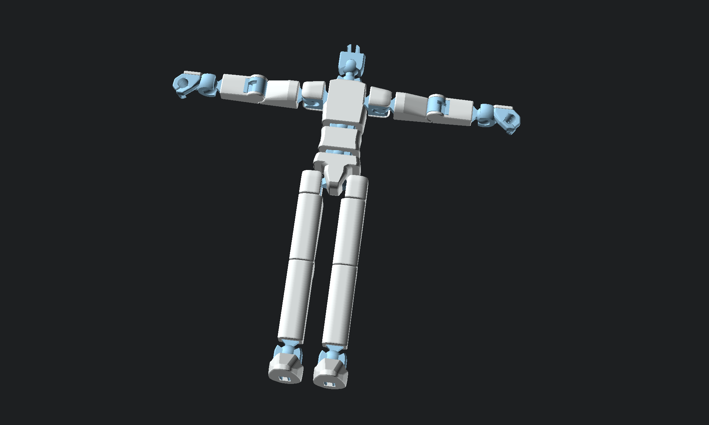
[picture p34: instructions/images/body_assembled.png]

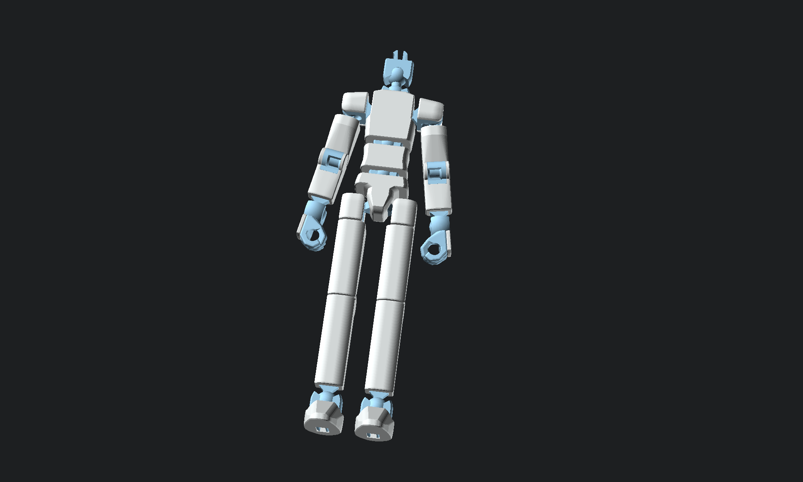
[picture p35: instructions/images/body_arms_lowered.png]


### Head Assembly
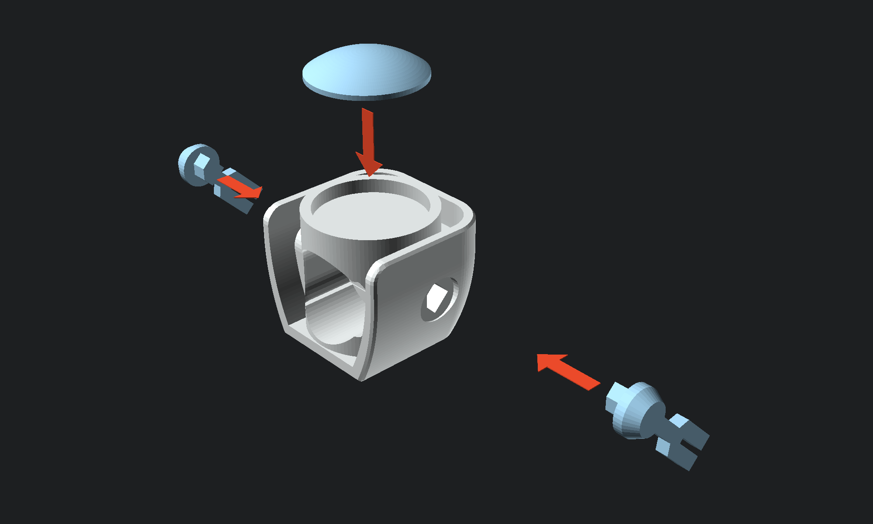
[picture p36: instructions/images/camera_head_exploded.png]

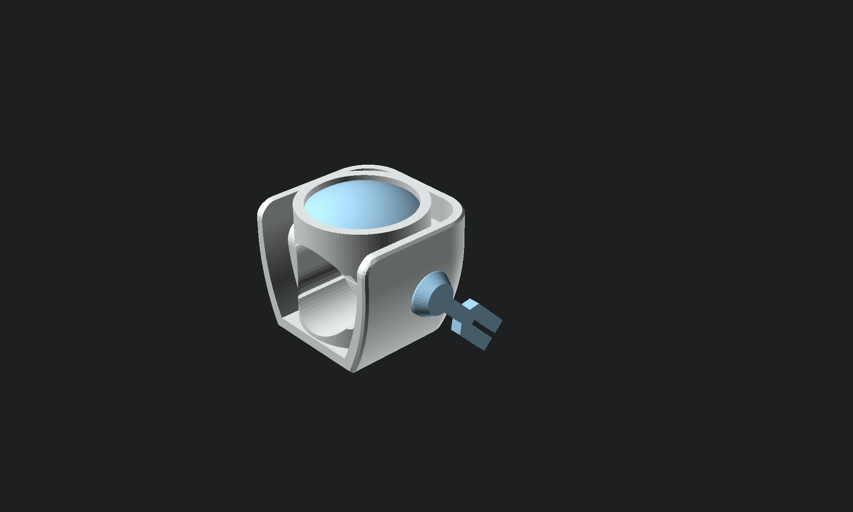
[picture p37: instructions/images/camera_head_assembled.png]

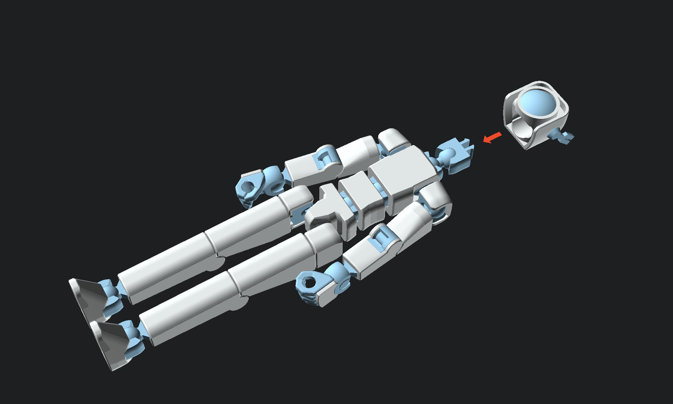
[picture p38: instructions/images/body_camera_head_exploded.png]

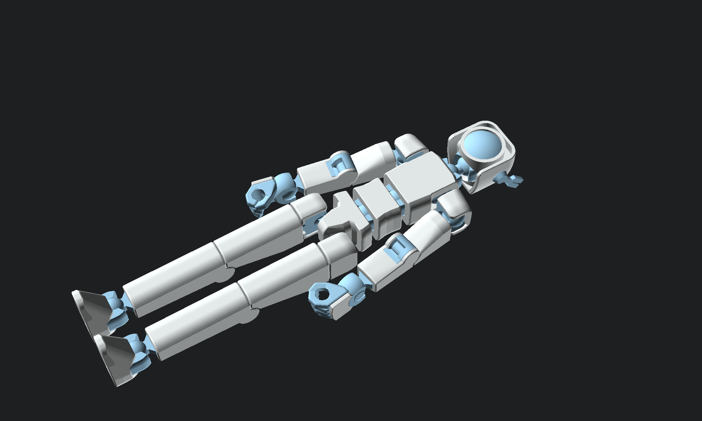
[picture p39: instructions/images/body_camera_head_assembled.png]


## Alternate Parts

### Space Head Assembly
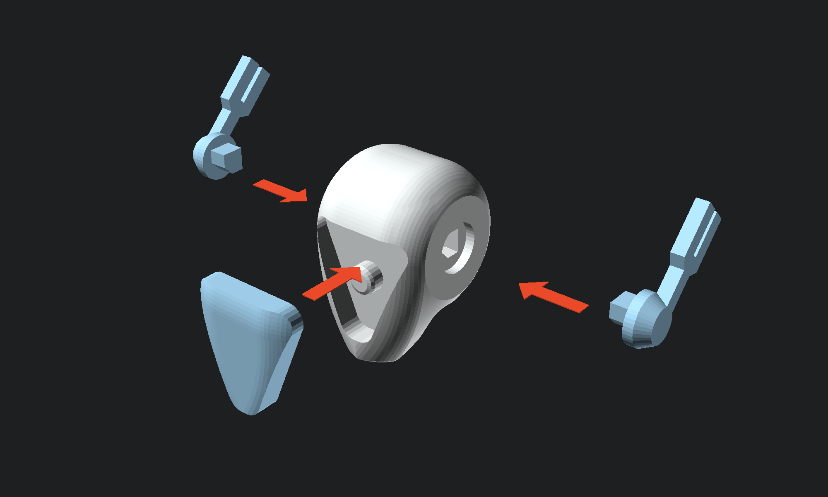
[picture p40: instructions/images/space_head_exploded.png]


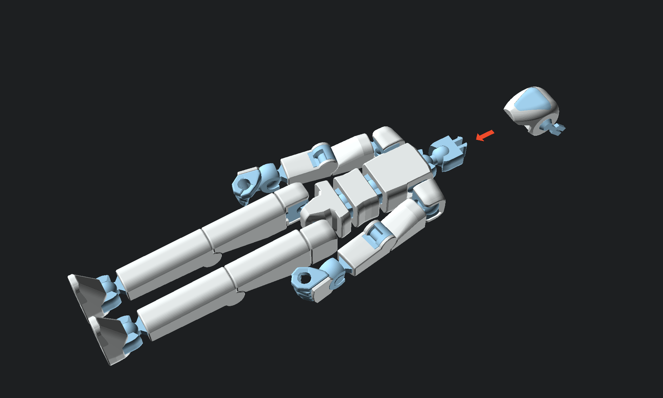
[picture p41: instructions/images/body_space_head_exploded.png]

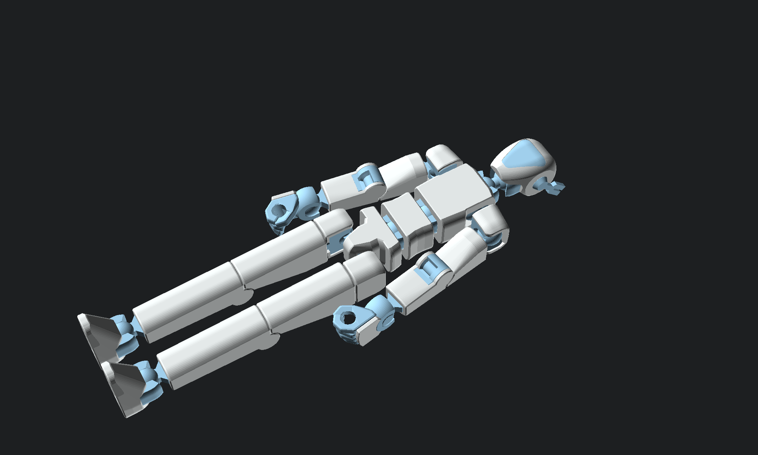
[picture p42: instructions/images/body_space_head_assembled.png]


### Wing Clip



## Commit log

2023-06-11 Added v1.0 objects
    [assembled.scad, body.scad, common.scad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]
2023-06-17 Added assembly notes and images to readme
2023-06-17 Added more notes for printing; guide to files in repo
2023-07-02 Updates to improve tolerances and assembly
    [assembled.scad, body.scad, common.scad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]
2023-07-16 Improved hand code and refactored
    [arms.scad, assembled.scad, body.scad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]
2023-10-15 Assembly improvements (#3)
    * Improved assembly and code organization
    * Cleanup based on review
    * Removed unused code
    [arms.scad, assembled.scad, body.scad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]
2023-10-17 Added pointing hand, removed duplicate code (#4)
    [common.scad, hands.scad]
2024-04-27 Better body (#5)
    * Added pointing hand, removed duplicate code
    * Improve body form
    * Faceted body parts draft 1
    * Made all the armor round
    * Cleaned up code
    * Replaced tabs with spaces
    * Replaced tabs with spaces
    * Simplified hand armor
    * Re-enabled hand preview code
    [arms.scad, assembled.scad, body.scad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]
2024-05-04 Assembly guide (#6)
    * Added assembly guide, part improvements, refactoring
    * Added assembly guide, part improvements, refactoring
    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
    [arms.scad, assembled.scad, assembly image map.scad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]
2024-06-10 Refinements (#7)
    * Refined some parts
    * Export script can work with non-preview openscad
    * Updated image export script to python
    * Project images, readme improvements, multi-platform export test
    * Updated submodule
    * Re-imported submodule
    * Updated docs and folder structure
    * Renamed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
    [arms.scad, assembly image map.scad, assembly.scad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]
2024-06-13 Refactor (#9)
    * Update docs, name, and removed unused script code
    * Addressed typos
    * Updated docs, minor refactoring
    [arms.scad, hands.scad, legs.scad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]
2024-06-22 Alternate head and export improvements (#11)
    * Removed submodule
    * Re-added utilites submodule
    * Alternate head and export script improvements
    * Export script cleanup, readme additions
    * Export improvements, improved head code
    * Updated assembly guide with new head
    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
    [antenna.scad, assembly image map.scad, assembly.scad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]
2024-08-03 Back attach (#12)
    * Script improvements, part refinements
    * Better wing attach code, improved export script
    * Improved export config
    * Improved torso generation images
    * Removed debug code
    [assembly image map.scad, assembly.scad, body.scad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]
2025-03-09 Improved wing clip (#13)
    [assembly image map.scad, assembly.scad, body.scad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]
2025-03-09 Fix indentation (#14)
    * Improved wing clip
    * Minor cleanup
    [body.scad]
